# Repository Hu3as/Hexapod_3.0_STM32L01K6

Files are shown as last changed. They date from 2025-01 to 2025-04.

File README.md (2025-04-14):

## <div align="center">Hexapod Based on STM32 Microcontroller</div>

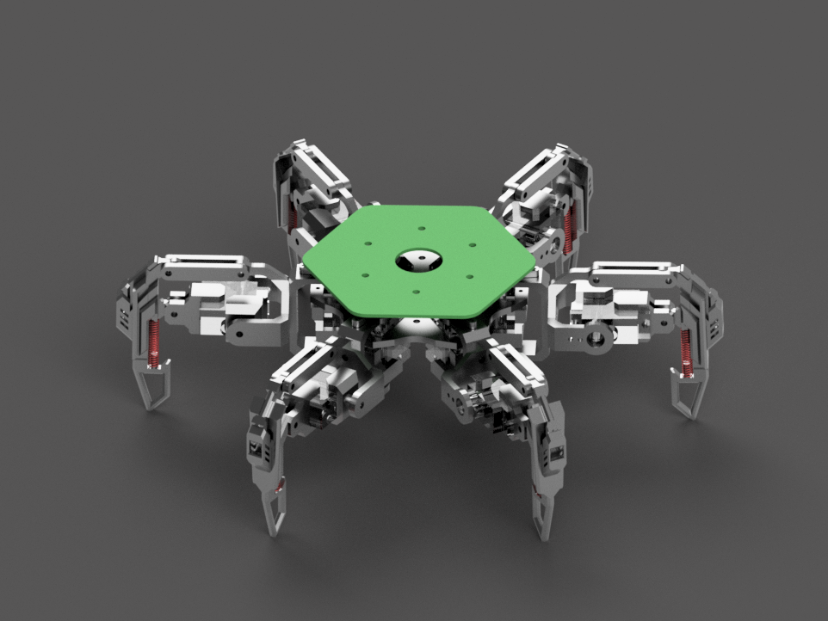
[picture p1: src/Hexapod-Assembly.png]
Hexapod_Render


Designed and built for an engineering thesis, this six-legged walking robot is controlled via Bluetooth or an nRF module. As part of the project, a PCB was designed and fabricated, and the software was developed. The robot's structure was 3D printed.

The repository includes KiCad files for the PCB and a project in STM Cube IDE.

<div style="text-align: center;">
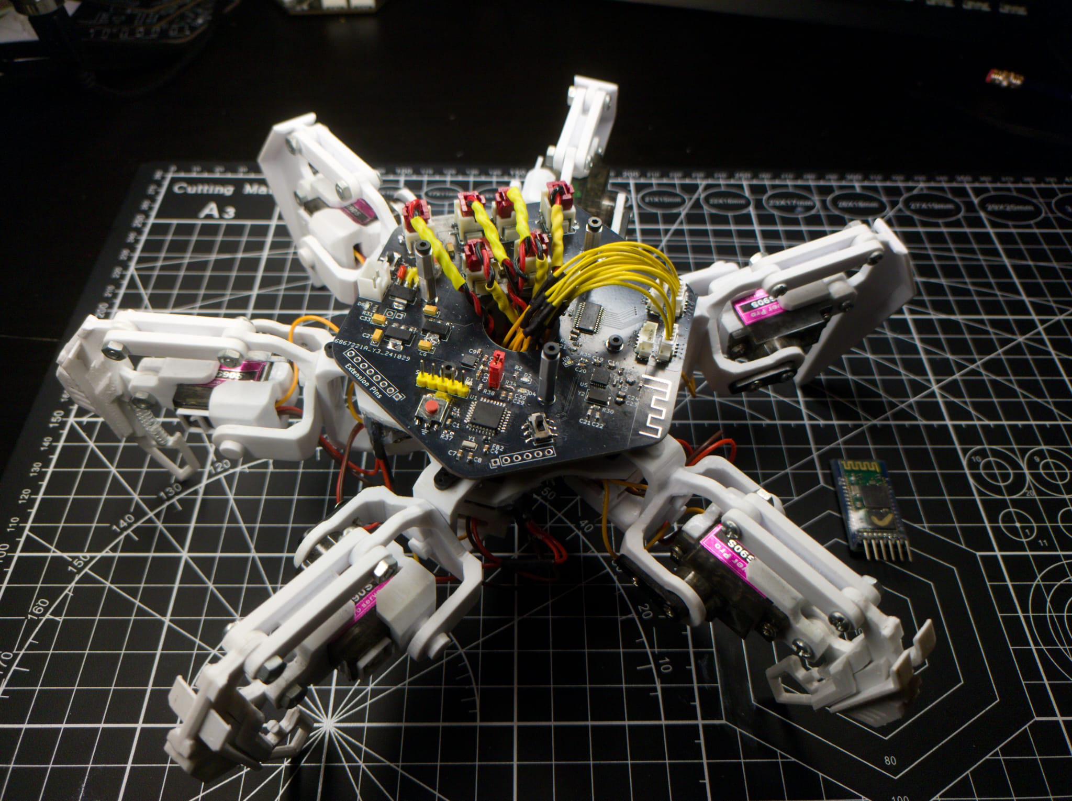
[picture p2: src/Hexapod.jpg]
HexapodPhoto

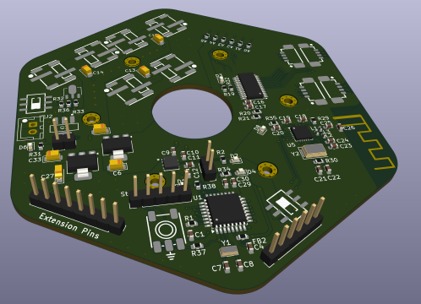
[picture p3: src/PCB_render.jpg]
PCBRender

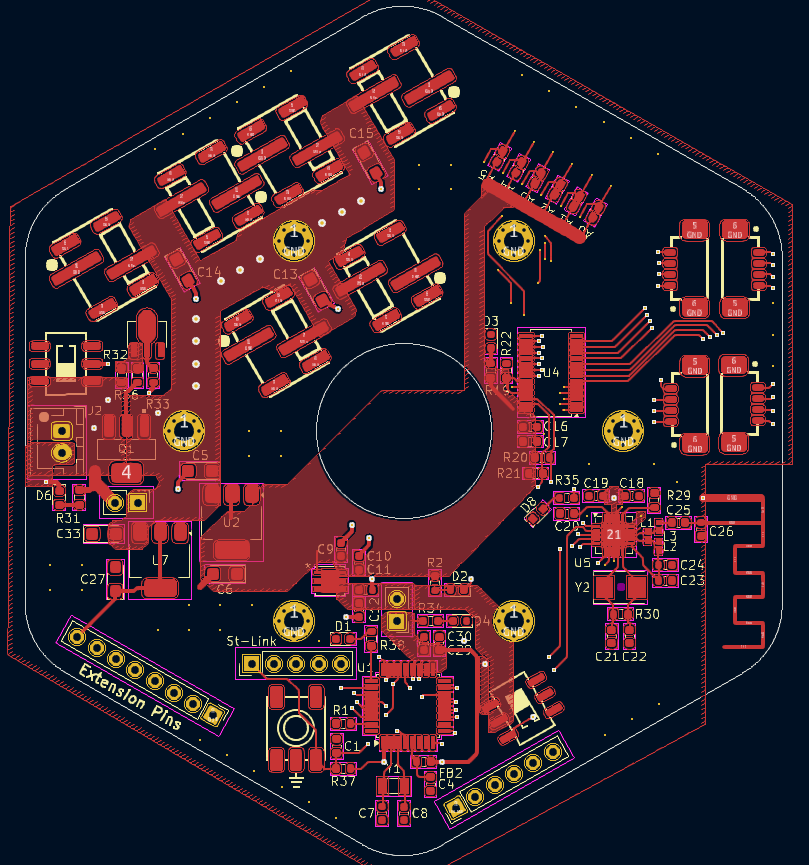
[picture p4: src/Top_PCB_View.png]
PCBTOP

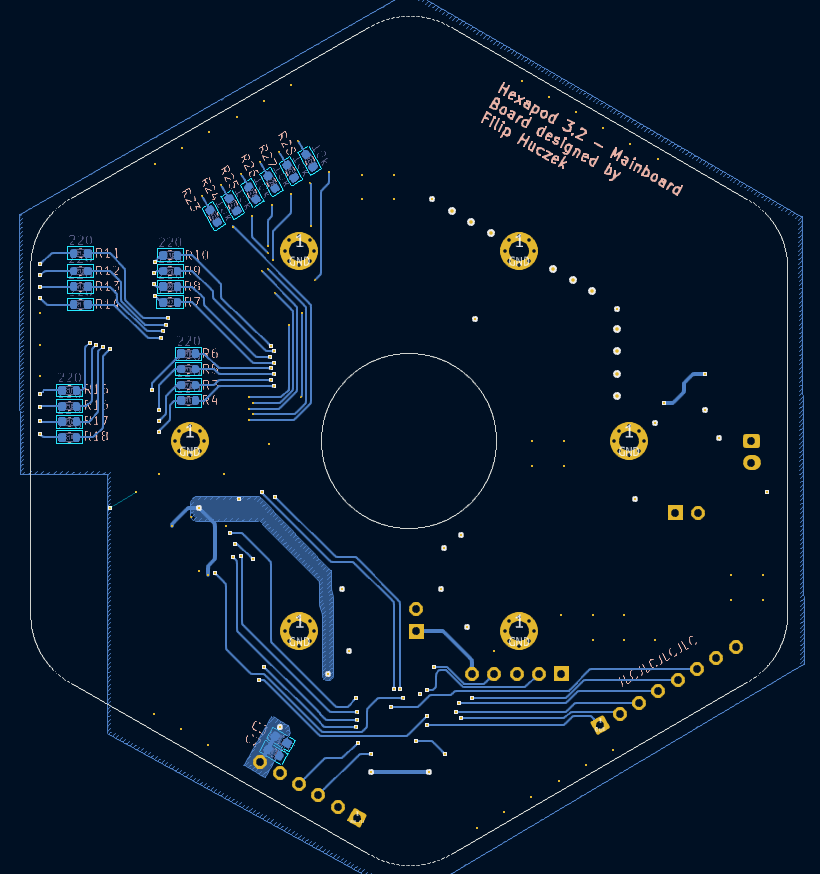
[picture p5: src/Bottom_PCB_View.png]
PCBBOT

</div>

### Components used:

- <b>Microcontroller:</b> STM32 L031K6T6

- <b>PWM Driver:</b> PCA9685PW

- <b>Bluetooth:</b> HC-05

- <b>nRF:</b> NRF24L01+ 2.4GHz

- <b>Buck Converters:</b> 8.4V → 6V

- <b>Transistors, Regulators, resistors, capacitors and other primary electronic components</b>

- <b>PWM Servos:</b> MG90S

<div style="text-align: center;">
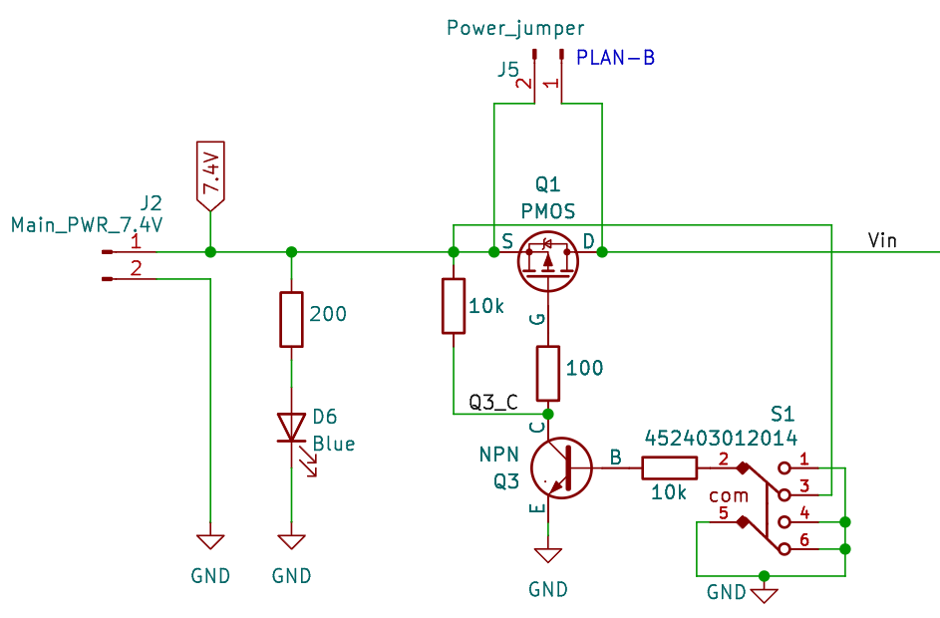
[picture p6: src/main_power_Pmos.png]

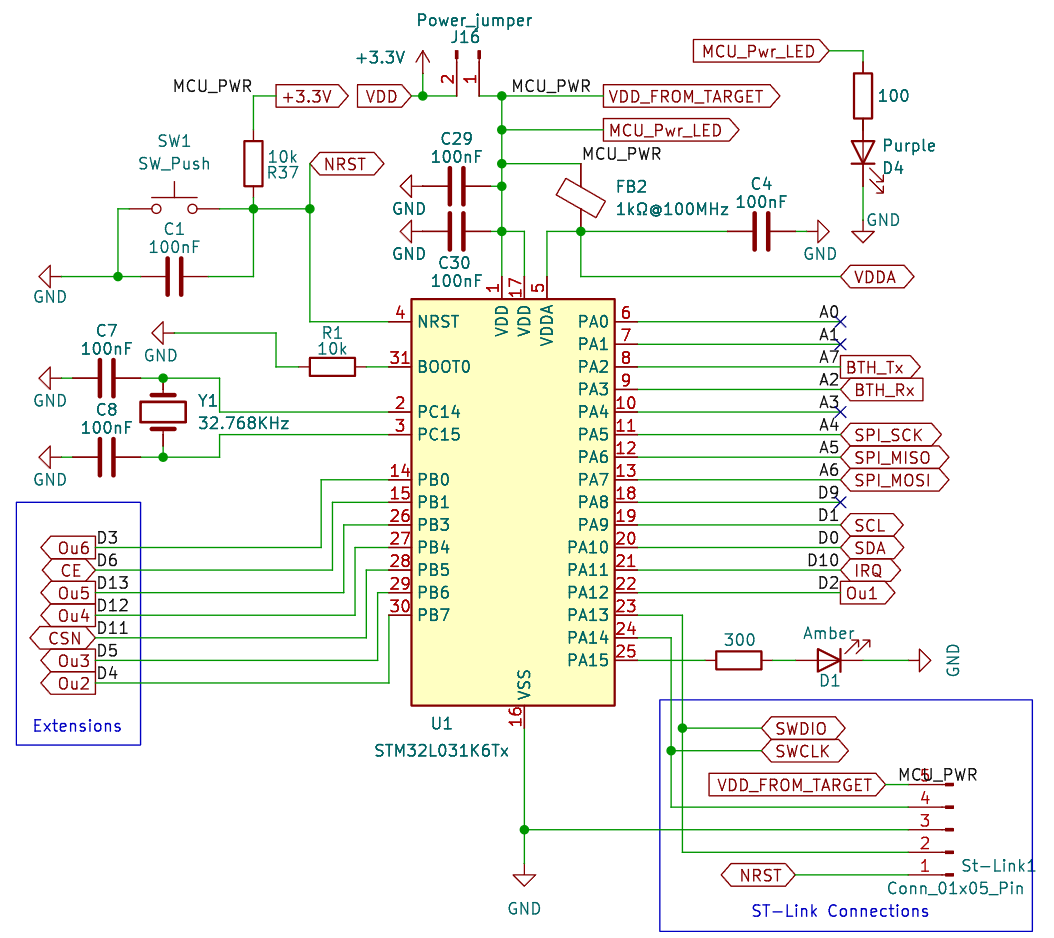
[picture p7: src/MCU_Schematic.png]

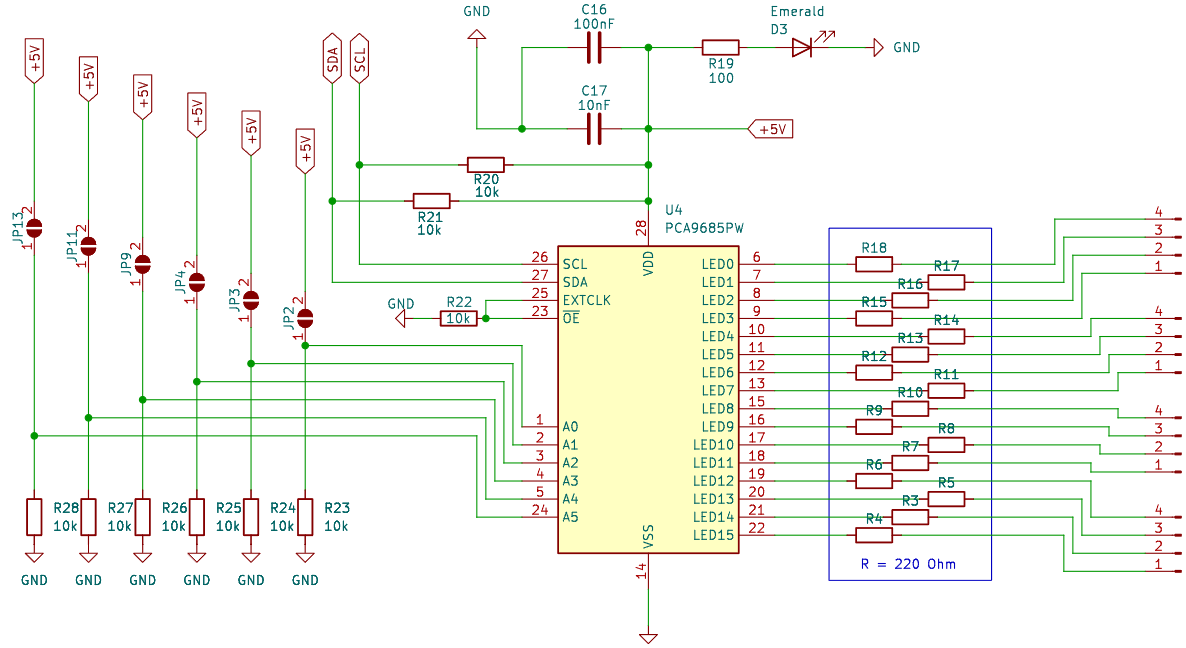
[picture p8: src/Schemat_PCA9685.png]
PCA

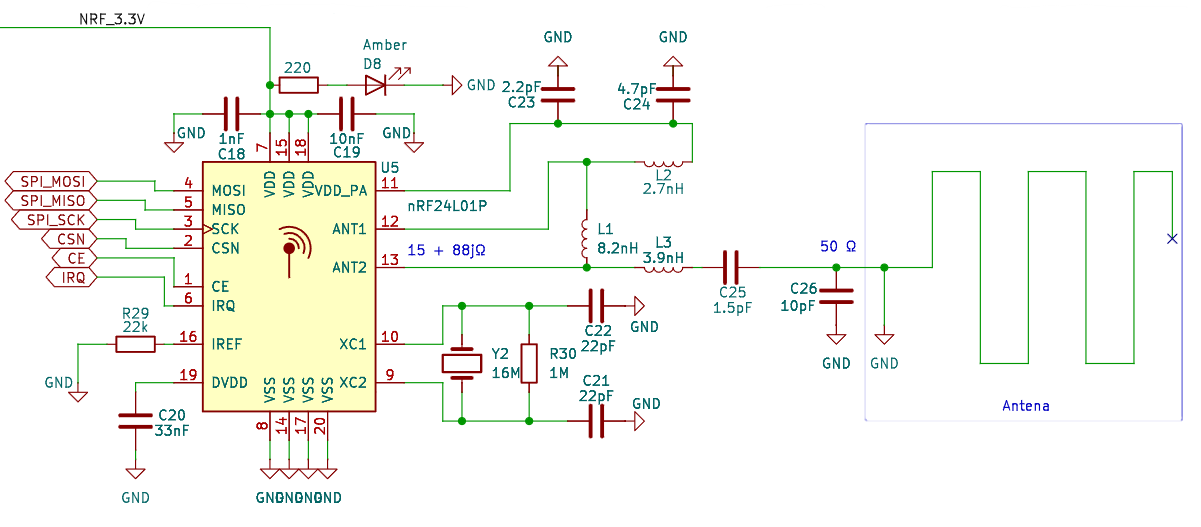
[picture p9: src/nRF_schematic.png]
nRF

</div>

### <div align="center">Software </div>

The software operates through communication via I2C, SPI, and UART with the respective components: the PWM driver, nRF module, and Bluetooth. The software includes an algorithm responsible for moving the robot's legs in Cartesian space. The robot is capable of moving forward, backward, and rotating.

### Software Structure:

<div style="text-align: center;">
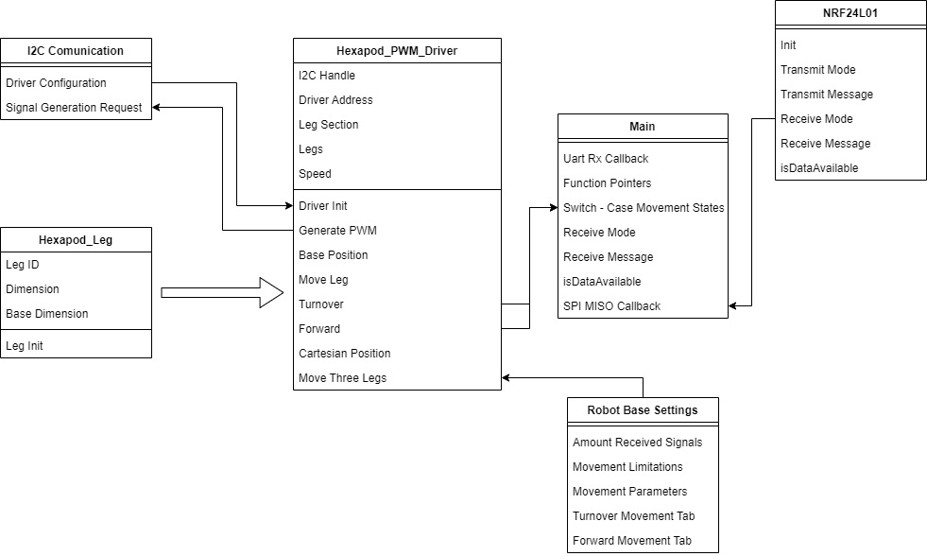
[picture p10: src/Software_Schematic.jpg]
SoftDiag

</div>

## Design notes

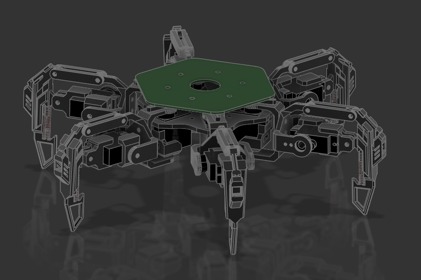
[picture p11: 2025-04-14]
src/Hexapod_Assmbly.jpg

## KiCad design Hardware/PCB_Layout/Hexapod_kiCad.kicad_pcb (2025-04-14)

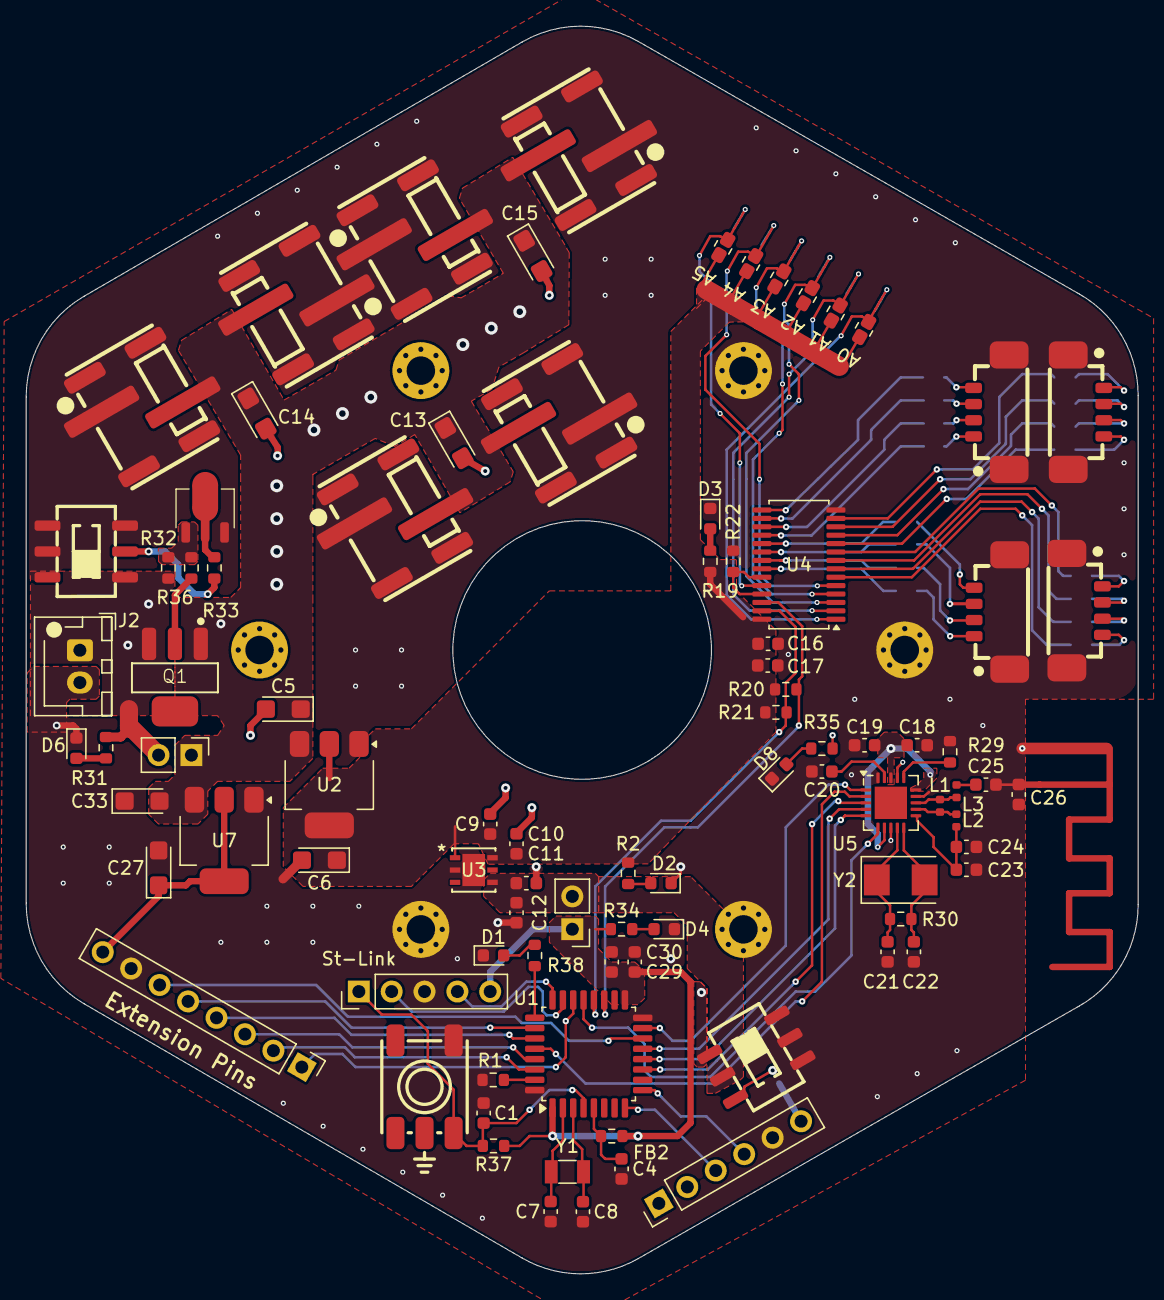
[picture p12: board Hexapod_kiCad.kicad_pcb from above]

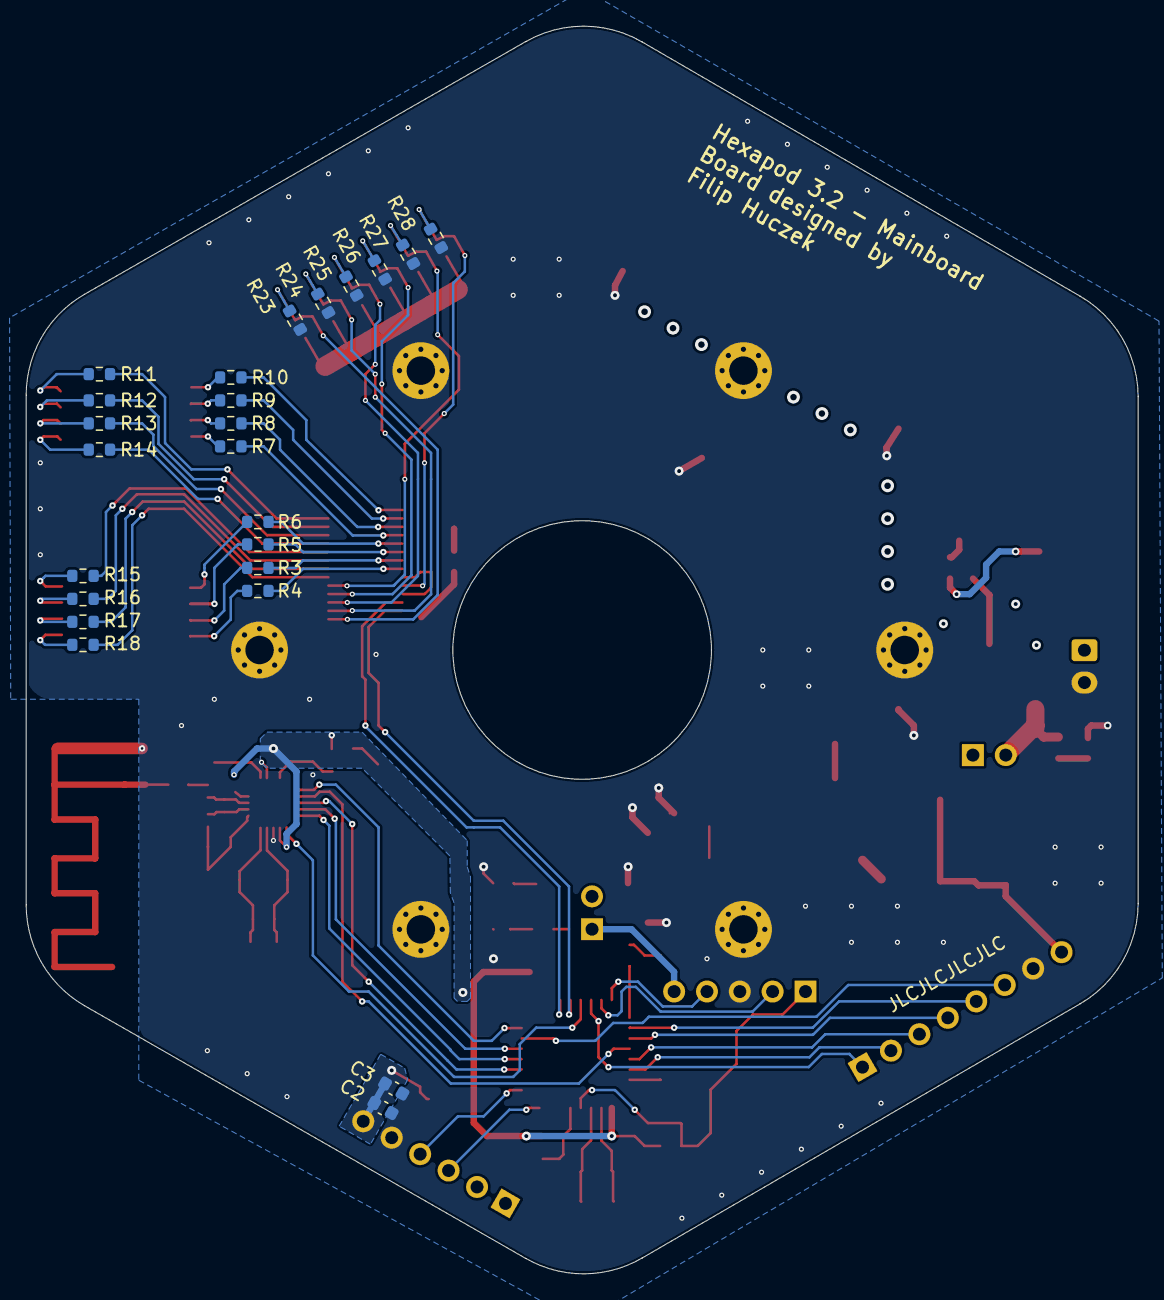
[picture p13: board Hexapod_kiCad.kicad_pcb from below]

Board: 2 copper layers, 86.0 x 96.5 mm, 119 parts (24 on the bottom side), 89 nets.

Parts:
C1, C4, C7, C8, C10, C12, C16, C29, C30: 100nF; C_0603_1608Metric
C2, C17, C19: 10nF; C_0603_1608Metric
C3, C18: 1nF; C_0603_1608Metric
C5, C6, C27, C33: 10uF; CP_EIA-3216-18_Kemet-A
C9, C11: 1uF; C_0603_1608Metric
C13, C14, C15: 220nF; CP_EIA-3216-18_Kemet-A
C20: 33nF; C_0603_1608Metric
C21, C22: 22pF; C_0603_1608Metric
C23: 2.2pF; C_0603_1608Metric
C24: 4.7pF; C_0603_1608Metric
C25: 1.5pF; C_0603_1608Metric
C26: 10pF; C_0603_1608Metric
D1: AsUWish; LED_0603_1608Metric
D2: Red; LED_0603_1608Metric
D3: Emerald; LED_0603_1608Metric
D4: Purple; LED_0603_1608Metric
D6: Blue; LED_0603_1608Metric
D8: Amber; LED_0603_1608Metric
FB2: 1kΩ@100MHz; R_0603_1608Metric
H1, H2, H3, H4, H5, H6: MountingHole_Pad; MountingHole_2.2mm_M2_Pad_Via_withoutCourtyard
J1, J3, J12, J13, J14, J15: Servo_Power; Servo_Power_header
J2: Main_PWR_7.4V; JST_XH_B2B-XH-AM_1x02_P2.50mm_Vertical
J4: 01x06_Socket_Bluetooth; PinHeader_1x06_P2.54mm_Vertical
J5, J16: Power_jumper; PinHeader_1x02_P2.54mm_Vertical
J6, J7, J8, J9: Conn_01x04_Pin_Servo_PWM; Picoblade_1.25_footprint
J10: Conn_01x08_Pin; PinHeader_1x08_P2.54mm_Vertical
JP2, JP3, JP4, JP9, JP11, JP13: SolderJumper_2_Open; R_0603_1608Metric
L1: 8.2nH; L_0402_1005Metric
L2: 2.7nH; L_0402_1005Metric
L3: 3.9nH; L_0402_1005Metric
Q1: PMOS; PMOS_BSP170P-VB
Q3: NPN; 2N2222AU
R1, R20, R21, R22, R23, R24, R25, R26, R27, R28, R32, R33, R37: 10k; R_0603_1608Metric
R2: 150; R_0603_1608Metric
R3, R4, R5, R6, R7, R8, R9, R10, R11, R12, R13, R14, R15, R16, R17, R18, R35: 220; R_0603_1608Metric
R19, R34, R36: 100; R_0603_1608Metric
R29: 22k; R_0603_1608Metric
R30: 1M; R_0603_1608Metric
R31: 200; R_0603_1608Metric
R38: AsUWish; R_0603_1608Metric
S1, S2: 452403012014; Slider_G-Switch MS-22D28-G020_footprint
SW1: SW_Push; Reset_Button
St-Link: Conn_01x05_Pin; PinHeader_1x05_P2.54mm_Vertical
U1: STM32L031K6Tx; LQFP-32_7x7mm_P0.8mm
U2, U7: LD1117S50TR_SOT223; SOT-223-3_TabPin2
U3: LD39050PU33R; DFN6_3X3_STM
U4: PCA9685PW; TSSOP-28_4.4x9.7mm_P0.65mm
U5: nRF24L01P; QFN-20-1EP_4x4mm_P0.5mm_EP2.5x2.5mm
Y1: 32.768KHz; Crystal_SMD_3215-2Pin_3.2x1.5mm
Y2: 16M; Crystal_SMD_5032-2Pin_5.0x3.2mm

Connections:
7.4V: J2.1, J5.2, Q1.3 (S), R31.1, R32.1, S1.3
+3.3V: C11.2, C12.2, C29.2, C30.2, FB2.2, J16.1, J16.2, R34.1, R37.1, S2.2, St-Link.5, U1.1 (VDD), U1.17 (VDD), U3.4 (VOUT)
+5V: C6.1, C9.1, C10.1, C16.2, C17.2, JP2.2 (B), JP3.2 (B), JP4.2 (B), JP9.2 (B), JP11.2 (B), JP13.2 (B), R2.1, R19.1, R20.2, R21.2, U2.2 (VO), U3.1 (EN), U3.6 (VIN), U4.28 (VDD)
+5_EXT: C27.1, J10.8, U7.2 (VO)
/Driver/BL_3.3V: C2.2, C3.1, J4.6, S2.1
/Driver/NRF_3.3V: C18.1, C19.2, R35.1, S2.3, U5.7 (VDD), U5.15 (VDD), U5.18 (VDD)
/Q3_C: Q3.1 (C), R32.2, R36.2
BTH_Rx: J4.4, U1.9 (PA3)
BTH_Tx: J4.3, U1.8 (PA2)
CE: U1.15 (PB1), U5.1 (CE)
CSN: U1.28 (PB5), U5.2 (CSN)
GND: C1.1, C2.1, C3.2, C4.2, C5.2, C6.2, C7.1, C8.1, C9.2, C10.2, C11.1, C12.1, C13.2, C14.2, C15.2, C16.1, C17.1, C18.2, C19.1, C20.2, C21.2, C22.2, C23.2, C24.2, C25.2, C26.1, C26.2, C27.2, C29.1, C30.1, C33.1, D1.1 (K), D2.1 (K), D3.1 (K), D4.1 (K), D6.1 (K), D8.1 (K), H1.1, H2.1, H3.1, H4.1, H5.1, H6.1, J1.1, J1.3, J1.4, J1.5, J1.6, J2.2, J3.1, J3.3, J3.4, J3.5, J3.6, J4.5, J6.5, J6.6, J7.5, J7.6, J8.5, J8.6, J9.5, J9.6, J10.7, J12.1, J12.3, J12.4, J12.5, J12.6, J13.1, J13.3, J13.4, J13.5, J13.6, J14.1, J14.3, J14.4, J14.5, J14.6, J15.1, J15.3, J15.4, J15.5, J15.6, Q3.3 (E), R1.2, R22.1, R23.1, R24.1, R25.1, R26.1, R27.1, R28.1, R29.2, S1.1, S1.4, S1.5, S1.6, S2.4, S2.5, S2.6, SW1.1, St-Link.3, U1.16 (VSS), U1.32 (VSS), U2.1 (GND), U3.2 (GND), U3.7 (GND), U4.14 (VSS), U5.8 (VSS), U5.14 (VSS), U5.17 (VSS), U5.20 (VSS), U7.1 (GND)
IRQ: U1.21 (PA11), U5.6 (IRQ)
NRST: C1.2, R37.2, SW1.2, St-Link.1, U1.4 (NRST)
unnamed: C25.1, L3.1
unnamed: D1.2 (A), R38.2
unnamed: D2.2 (A), R2.2
unnamed: D3.2 (A), R19.2
unnamed: D4.2 (A), R34.2
unnamed: D6.2 (A), R31.2
unnamed: D8.2 (A), R35.2
unnamed: J6.1, R7.2
unnamed: J6.2, R8.2
unnamed: J6.3, R9.2
unnamed: J6.4, R10.2
unnamed: J7.1, R4.2
unnamed: J7.2, R3.2
unnamed: J7.3, R5.2
unnamed: J7.4, R6.2
unnamed: J8.1, R11.2
unnamed: J8.2, R12.2
unnamed: J8.3, R13.2
unnamed: J8.4, R14.2
unnamed: J9.1, R15.2
unnamed: J9.2, R16.2
unnamed: J9.3, R17.2
unnamed: J9.4, R18.2
unnamed: JP2.1 (A), R23.2, U4.1 (A0)
unnamed: JP3.1 (A), R24.2, U4.2 (A1)
unnamed: JP4.1 (A), R25.2, U4.3 (A2)
unnamed: JP9.1 (A), R26.2, U4.4 (A3)
unnamed: JP11.1 (A), R27.2, U4.5 (A4)
unnamed: JP13.1 (A), R28.2, U4.24 (A5)
unnamed: Q1.2 (G), R36.1
unnamed: Q3.2 (B), R33.1
unnamed: R33.2, S1.2
unnamed: R1.1, U1.31 (BOOT0)
unnamed: R38.1, U1.25 (PA15)
unnamed: C7.2, U1.2 (PC14), Y1.2
unnamed: C8.2, U1.3 (PC15), Y1.1
unnamed: R22.2, U4.23 (~OE), U4.25 (EXTCLK)
unnamed: R18.1, U4.6 (LED0)
unnamed: R17.1, U4.7 (LED1)
unnamed: R16.1, U4.8 (LED2)
unnamed: R15.1, U4.9 (LED3)
unnamed: R14.1, U4.10 (LED4)
unnamed: R13.1, U4.11 (LED5)
unnamed: R12.1, U4.12 (LED6)
unnamed: R11.1, U4.13 (LED7)
unnamed: R10.1, U4.15 (LED8)
unnamed: R9.1, U4.16 (LED9)
unnamed: R8.1, U4.17 (LED10)
unnamed: R7.1, U4.18 (LED11)
unnamed: R6.1, U4.19 (LED12)
unnamed: R5.1, U4.20 (LED13)
unnamed: R3.1, U4.21 (LED14)
unnamed: R4.1, U4.22 (LED15)
unnamed: L1.2, L2.2, U5.12 (ANT1)
unnamed: L1.1, L3.2, U5.13 (ANT2)
unnamed: C20.1, U5.19 (DVDD)
unnamed: R29.1, U5.16 (IREF)
unnamed: C23.1, C24.1, L2.1, U5.11 (VDD_PA)
unnamed: C22.1, R30.1, U5.10 (XC1), Y2.2
unnamed: C21.1, R30.2, U5.9 (XC2), Y2.1
Ou1: J10.1, U1.22 (PA12)
Ou2: J10.2, U1.30 (PB7)
Ou3: J10.3, U1.29 (PB6)
Ou4: J10.4, U1.27 (PB4)
Ou5: J10.5, U1.26 (PB3)
Ou6: J10.6, U1.14 (PB0)
SCL: R20.1, U1.19 (PA9), U4.26 (SCL)
SDA: R21.1, U1.20 (PA10), U4.27 (SDA)
SPI_MISO: U1.12 (PA6), U5.5 (MISO)
SPI_MOSI: U1.13 (PA7), U5.4 (MOSI)
SPI_SCK: U1.11 (PA5), U5.3 (SCK)
SWCLK: St-Link.4, U1.24 (PA14)
SWDIO: St-Link.2, U1.23 (PA13)
VDDA: C4.1, FB2.1, U1.5 (VDDA)
Vin: C5.1, C13.1, C14.1, C15.1, C33.2, J1.2, J3.2, J5.1, J12.2, J13.2, J14.2, J15.2, Q1.1 (D), U2.3 (VI), U7.3 (VI)

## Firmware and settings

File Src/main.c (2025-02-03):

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
/* Includes ------------------------------------------------------------------*/
#include "main.h"

/* USER CODE BEGIN Includes */
#include "Hexapod_Driver_PWM.h"
#include "Robot_Base_Settings.h"
/* USER CODE END Includes */

I2C_HandleTypeDef hi2c1;
UART_HandleTypeDef huart2;

/* USER CODE BEGIN PV */
Hexapod_PWM_Driver controller;
void (*ActionTable[STATES_AMOUNT])(Hexapod_PWM_Driver *controller);
uint8_t znak = 0;
uint8_t state = 0;
/* USER CODE END PV */

void SystemClock_Config(void);
static void MX_GPIO_Init(void);
static void MX_I2C1_Init(void);
static void MX_USART2_UART_Init(void);

/* USER CODE BEGIN PFP */
void ForwardMovement(Hexapod_PWM_Driver *controller) {
	state=znak;
}

void BackwardMovement(Hexapod_PWM_Driver *controller) {
	state=znak;
}

void TurnRight(Hexapod_PWM_Driver *controller) {
	state=znak;
}

void TurnLeft(Hexapod_PWM_Driver *controller) {
	state=znak;
}

void Pause(Hexapod_PWM_Driver * controller){
	state=znak;
}

void DefaultAction(Hexapod_PWM_Driver *controller) {
    // Blank or wrong message
}

void InitActionTable(Hexapod_PWM_Driver *controller) {
    for (int i = 0; i < STATES_AMOUNT; i++) {
        ActionTable[i] = DefaultAction;
    }
    ActionTable['F'] = ForwardMovement;
    ActionTable['B'] = BackwardMovement;
    ActionTable['R'] = TurnRight;
    ActionTable['L'] = TurnLeft;
    ActionTable['P'] = Pause;
}

/* USER CODE END PFP */

/* USER CODE BEGIN 0 */
void HAL_UART_RxCpltCallback(UART_HandleTypeDef *huart) {
    if (huart->Instance == USART2) {
    	(*ActionTable[znak])(&controller);


        HAL_UART_Receive_IT(&huart2, &znak, 1);
    }
}
/* USER CODE END 0 */

/**
  * @brief  The application entry point.
  * @retval int
  */
int main(void) {
    /* MCU Configuration--------------------------------------------------------*/

    /* Reset of all peripherals, Initializes the Flash interface and the Systick. */
    HAL_Init();

    /* Configure the system clock */
    SystemClock_Config();

    /* Initialize all configured peripherals */
    MX_GPIO_Init();
    MX_I2C1_Init();
    MX_USART2_UART_Init();

    /* USER CODE BEGIN 2 */
    Hexapod_PWM_Driver_Init(&controller, &hi2c1, 0x80);  // PCA9685 address
    Hexapod_PWM_Driver_BasePosition(&controller);

    HAL_UART_Receive_IT(&huart2, &znak, 1);

    InitActionTable(&controller);
    HAL_Delay(1000);

    /* USER CODE END 2 */

    /* Infinite loop */
    /* USER CODE BEGIN WHILE */
    while (1) {

    	switch (state) {
			case 'F':
				Hexapod_PWM_Driver_Forward(&controller, 1);
				break;
			case 'B':
				Hexapod_PWM_Driver_Forward(&controller, -1);
				break;
			case 'R':
				Hexapod_PWM_Driver_Turnover(&controller, 1);
				break;
			case 'L':
				Hexapod_PWM_Driver_Turnover(&controller, -1);
				break;
			case 'P':
				Hexapod_PWM_Driver_BasePosition(&controller);
				break;
			default:

				break;
		}

    /* USER CODE END WHILE */

    /* USER CODE BEGIN 3 */
	}
  /* USER CODE END 3 */
}

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


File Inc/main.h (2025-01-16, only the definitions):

#define TMS_Pin GPIO_PIN_13
#define TMS_GPIO_Port GPIOA
#define TCK_Pin GPIO_PIN_14
#define TCK_GPIO_Port GPIOA

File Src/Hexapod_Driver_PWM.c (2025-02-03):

#include <Hexapod_Driver_PWM.h>
#include <Robot_Base_Settings.h>
#include <stdbool.h>

// Initialize a single leg with its ID and default position
void Hexapod_Leg_init( Hexapod_Leg *leg, int id){

	// Leg base coordinates initialization (X and Z coordinates for each leg)
	// Leg IDs:   		  L0      L1      L2      L3      L4      L5
	float X_Legs[6] = { -10.0,  -5.0,   -10.0,  -10.0,   15.0,   10.0};
	float Z_Legs[6] = { -40.0,  -35.0,  -40.0,  -40.0,  -40.0,  -30.0};

	leg->leg_id = id;
	leg->dimension[0] = X_Legs[(int)(id/2)];
	leg->dimension[1] = Z_Legs[(int)(id/2)];
	 // Store the base position of the leg
	leg->base_dim[0] = X_Legs[(int)(id/2)];
	leg->base_dim[1] = Z_Legs[(int)(id/2)];

}

/* Initialize the PWM driver for the Hexapod */
void Hexapod_PWM_Driver_Init(Hexapod_PWM_Driver *driver, I2C_HandleTypeDef *i2c, uint8_t driver_address) {

    driver->i2c = i2c;
	driver->driver_address = driver_address;


	 // Initialize leg section mapping
	for (int i = 0; i < 3; i++) {
	    driver->leg_section[i][0] = 4 * i;
	    driver->leg_section[i][1] = 4 * i + 2;
	}

	int leg_index = 0;
	for(int i = 0; i< 2; i++){		// Initialize all legs with base ID values
		for(int j = 0; j<3; j++ ){
			Hexapod_Leg_init(&driver->legs[leg_index], driver->leg_section[j][i]);
			leg_index++;
		}
	}

	// Configure PWM driver using I2C
	uint8_t oldMode = 0;
	uint8_t NewMode = ((oldMode & 0x7F) | 0x10);
	uint8_t buffor[2] = {PCA9685_MODE1, NewMode};

	HAL_I2C_Master_Transmit(driver->i2c, driver_address, PCA9685_MODE1, 1, 1);
	HAL_I2C_Master_Transmit(driver->i2c, driver_address, buffor, 2, 1);
	buffor[1] = 3; // Hard-coded prescaler
	HAL_I2C_Master_Transmit(driver->i2c, driver_address, buffor, 2, 1);
	buffor[1] = oldMode;
	HAL_I2C_Master_Transmit(driver->i2c, driver_address, buffor, 2, 1);
	HAL_Delay(10);
	buffor[1] = (oldMode | 0xA1);
	HAL_I2C_Master_Transmit(driver->i2c, driver_address, buffor, 2, 1);

}
/* Generate a PWM signal for a given servo */
void Hexapod_PWM_Driver_Generate_PWM_Signal(Hexapod_PWM_Driver *driver, uint8_t id, uint16_t on, uint16_t off) {
    uint8_t buffor[5] = {
        (uint8_t)(0x06 + 4 * id),
        (uint8_t)(on),
        (uint8_t)(on >> 8),
        (uint8_t)(off),
        (uint8_t)(off >> 8)
    };

    HAL_I2C_Master_Transmit(driver->i2c, driver->driver_address, buffor, 5, 1);
}

/* Map an angle to PWM range */
float Hexapod_PWM_Driver_Map(float angle, float x, float y, float inputMIN, float inputMAX) {
    return (angle - x) * (inputMAX - inputMIN) / (y - x) + inputMIN;
}

/* Move a servo to a specific angle */
void Hexapod_PWM_Driver_MoveServo(Hexapod_PWM_Driver *driver, uint8_t id, float horizontal_ang, float vertical_ang){

	bool isVertical = id & 1;
	uint8_t angle = isVertical ? vertical_ang : horizontal_ang;
	uint8_t min_angle = isVertical ? VERT_MIN : HORIZ_MIN;
	uint8_t max_angle = isVertical ? VERT_MAX : HORIZ_MAX;

	if (angle != IGNORE_ANGLE && angle >= min_angle && angle <= max_angle) {
		Hexapod_PWM_Driver_Generate_PWM_Signal(driver, id, 0, 4095 - (16 * Hexapod_PWM_Driver_Map(angle, 0, 180, 130, 230)));
	}
}

/*___________________INVERSE KINEMATIC_________________________*/
void Hexapod_PWM_Driver_CartesianPosition(Hexapod_PWM_Driver *driver, int leg_id, float X, float Z) {
    Z += 43.0;
    float angle_OZ = ( (asin(Z / 27.7)) * (180 / M_PI) ) + 90.0;
    float angle_OX = ( (asin(X / 65.0)) * (180 / M_PI) ) + 90.0;

    Hexapod_PWM_Driver_MoveServo(driver, leg_id, angle_OX, 255);	//hor
    Hexapod_PWM_Driver_MoveServo(driver, leg_id+1, 255, angle_OZ);//ver
/*_________Cartesian moving range___________*/

//			X-Axis:		< -20 ; 20 >
//			Z-Axis:		< -63 ; -29>
//			Y-Axis: 	The y-axis is based on the
//						remaining coordinates, and due to the
//						construction fact, it is not required
//						for correct movement.
/*__________________________________________*/
}


/* Move the hexapod to its base position */
void Hexapod_PWM_Driver_BasePosition(Hexapod_PWM_Driver *driver) {
	for(int i = 0; i<6; i++){
		Hexapod_PWM_Driver_CartesianPosition(driver, driver->legs[i].leg_id, driver->legs[i].base_dim[0], driver->legs[i].base_dim[1]);
	}
}

/* Move three legs to the specified coordinates with damping and elasticity */
void Hexapod_PWM_Driver_MovetoThreeLegs(Hexapod_PWM_Driver *driver, int legs[3], float *endX, float *endZ) {
    float currentX[3], currentZ[3], velocityX[3] = {0}, velocityZ[3] = {0};
    float stiffness = STIFFNESS;  		//def 0.5	//slow 0.1
    float damping = DAMPING;    		//def 0.6	//slow 0.4
    int max_steps = ITERATION_STEPS;  	//def 30	//slow 150
    int completed[3] = {0, 0, 0};


    // Initialize positions
    for (int i = 0; i < 3; i++) {
        currentX[i] = driver->legs[legs[i]].dimension[0];
        currentZ[i] = driver->legs[legs[i]].dimension[1];
    }

    // Apply dynamic movement with damping
    for (int step = 0; step < max_steps; step++) {
        for (int i = 0; i < 3; i++) {
            if (!completed[i]) {
                // Force attracting towards the target position
                float forceX = (endX[i] - currentX[i]) * stiffness;
                float forceZ = (endZ[i] - currentZ[i]) * stiffness;

                // Velocity update considering damping
                velocityX[i] = (velocityX[i] + forceX) * damping;
                velocityZ[i] = (velocityZ[i] + forceZ) * damping;

                // Leg position update
                currentX[i] += velocityX[i];
                currentZ[i] += velocityZ[i];

                driver->legs[legs[i]].dimension[0] = currentX[i];
                driver->legs[legs[i]].dimension[1] = currentZ[i];

                Hexapod_PWM_Driver_CartesianPosition(driver, driver->legs[legs[i]].leg_id, currentX[i], currentZ[i]);

                // If the leg is close to the target and the velocity is very small → stop the movement
                if (fabs(currentX[i] - endX[i]) < 0.1 && fabs(currentZ[i] - endZ[i]) < 0.1 && fabs(velocityX[i]) < 0.01 && fabs(velocityZ[i]) < 0.01) {
                    completed[i] = 1;
                }
            }
        }
    }
}
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

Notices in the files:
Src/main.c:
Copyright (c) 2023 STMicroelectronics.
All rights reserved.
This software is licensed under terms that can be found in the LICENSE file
